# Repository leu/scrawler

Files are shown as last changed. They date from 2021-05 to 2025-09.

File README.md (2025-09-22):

# The Scrawler
The name of this keyboard is the Scrawler.

It was inspired by this YouTube video: https://www.youtube.com/watch?v=thOifuHs6eY. It was born of wanting to experiment with a hexagonal tiling layout for keyboards. I currently have no plans to continue work on this project, as it is time consuming and many of the challenges are in the domain of material science and physical design, and I would rather spend my time in my personal specialisation of programming and computer science. But in case you have any questions, feel free to reach out to me at in.lieu.of.leu@gmail.com!

This repository contains all of my notes, PCB designs, and CAD files for 3D print for the Scrawler.

Second prototype:


First prototype:
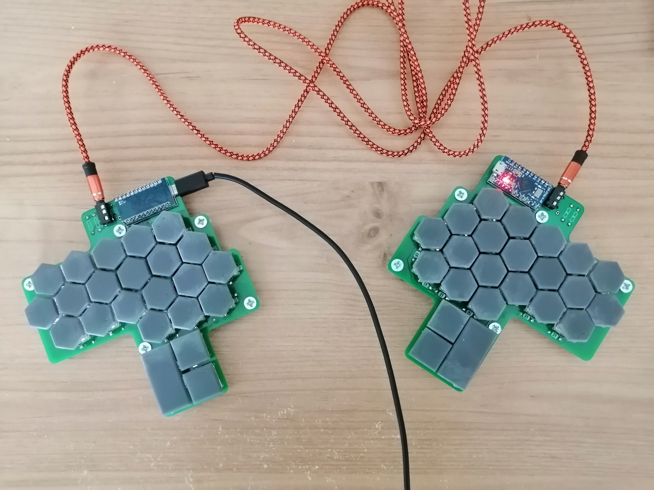
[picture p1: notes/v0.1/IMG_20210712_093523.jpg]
prototype both sides

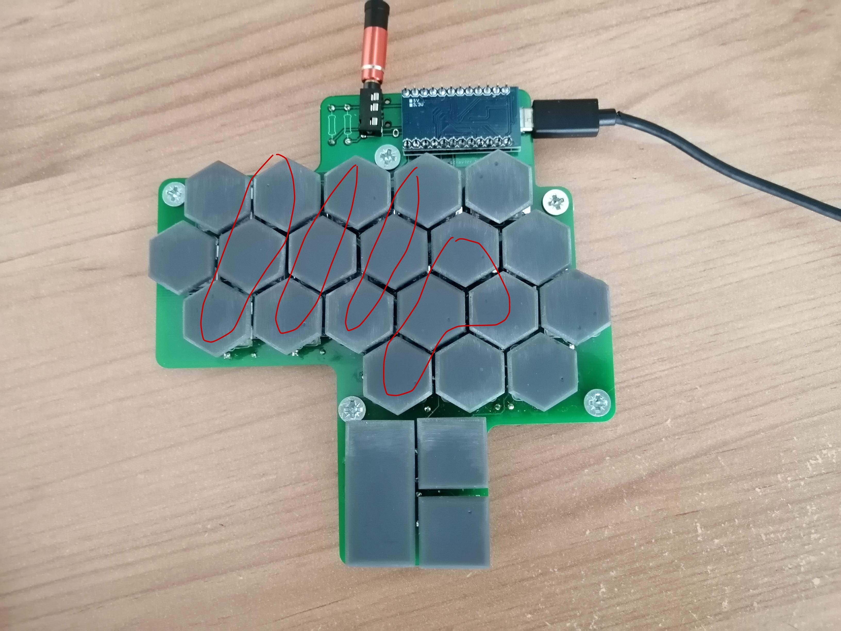
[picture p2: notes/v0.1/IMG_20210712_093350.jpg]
prototype left side

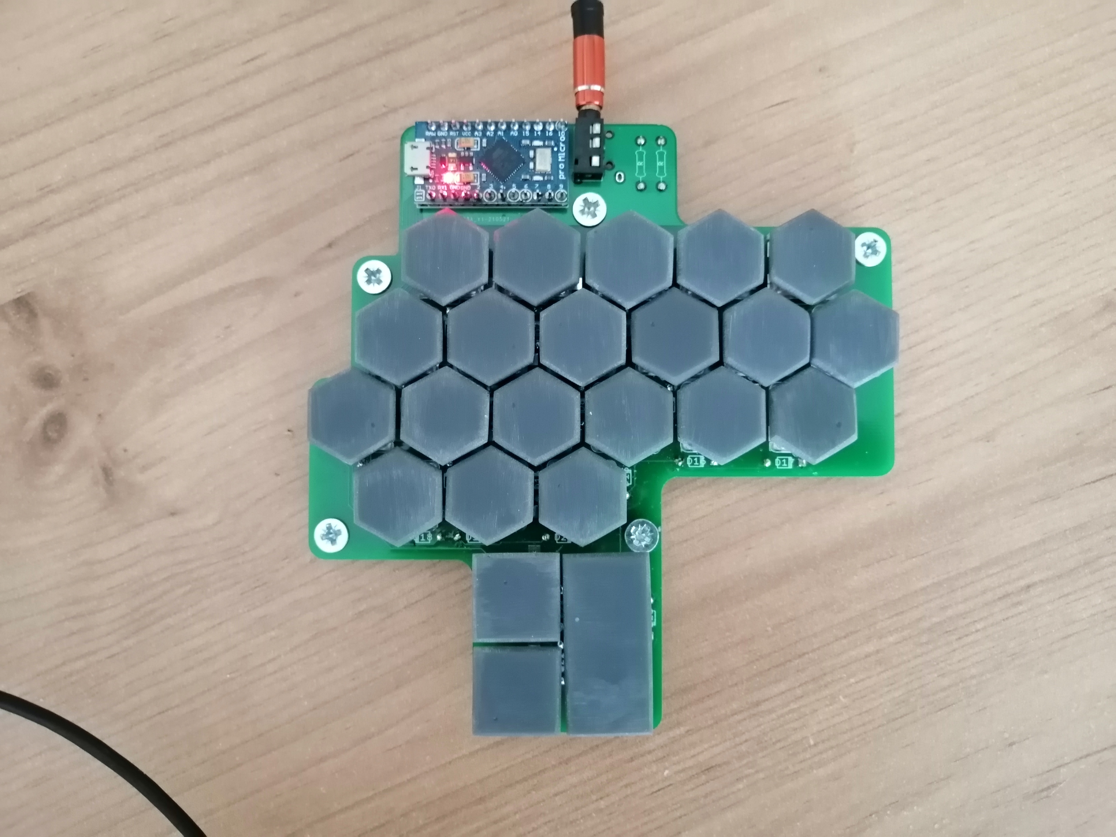
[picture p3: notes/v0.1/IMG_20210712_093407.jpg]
prototype right side


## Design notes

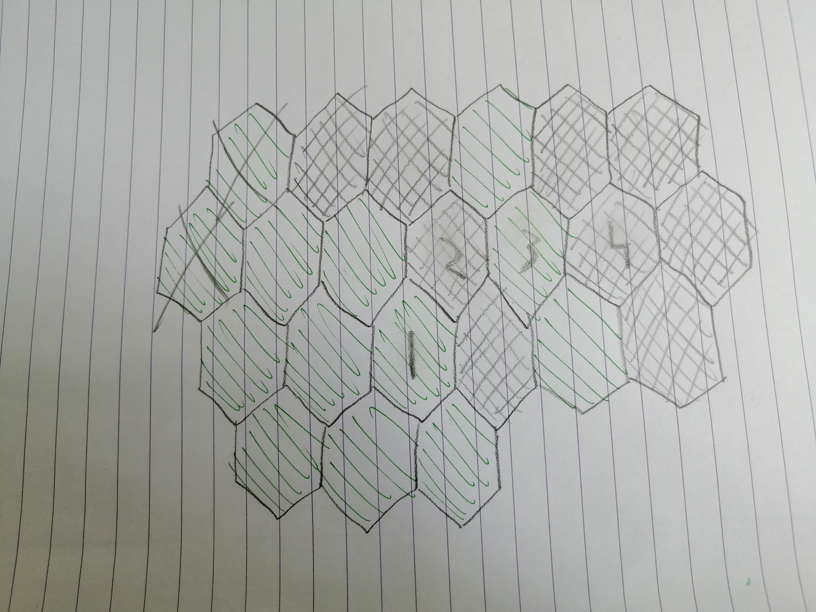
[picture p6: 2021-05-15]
notes/v0.1/layout.jpg

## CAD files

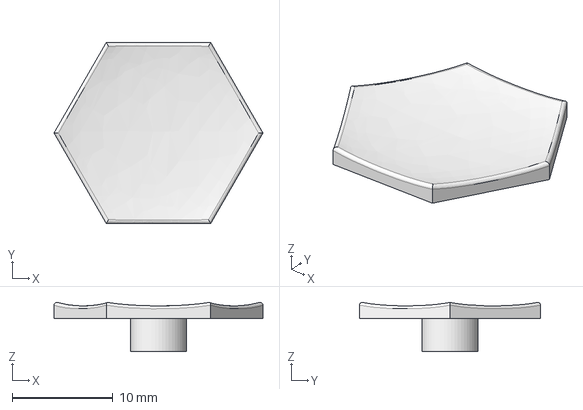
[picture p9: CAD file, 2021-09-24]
v1/keycaps/hexagonal/hex_keycap.FCStd
20.8 x 18.0 x 4.90 mm

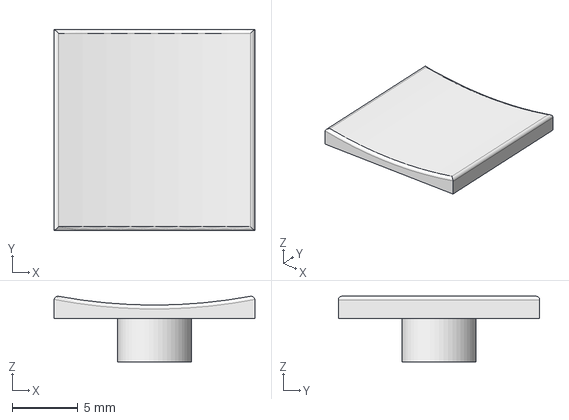
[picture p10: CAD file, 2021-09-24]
v1/keycaps/square/square.FCStd
15.2 x 15.2 x 4.97 mm

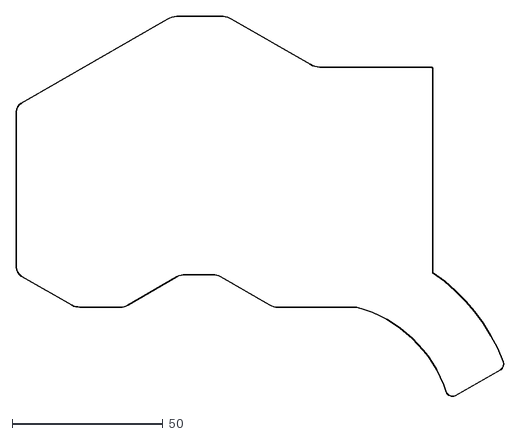
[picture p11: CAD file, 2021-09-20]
v1/plate/top_plate.dxf
161.9 x 126.1

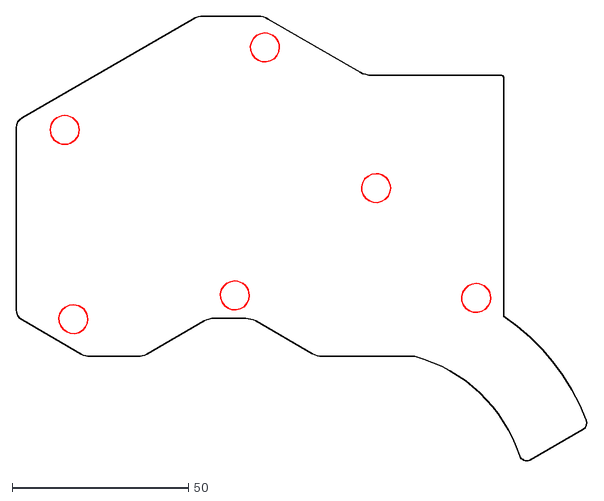
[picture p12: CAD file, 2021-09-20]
v1/plate/bottom_plate.dxf
161.9 x 126.1

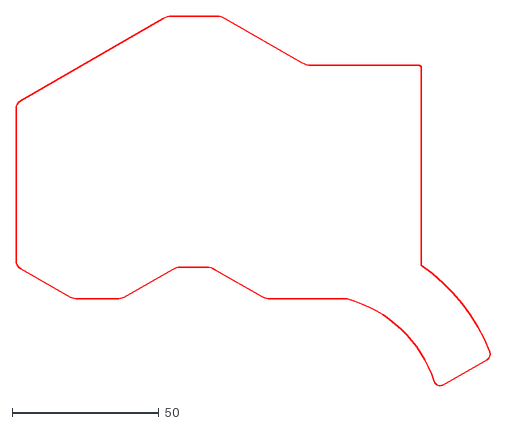
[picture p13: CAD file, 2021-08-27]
v1/plate/drawing.dxf
161.9 x 126.1

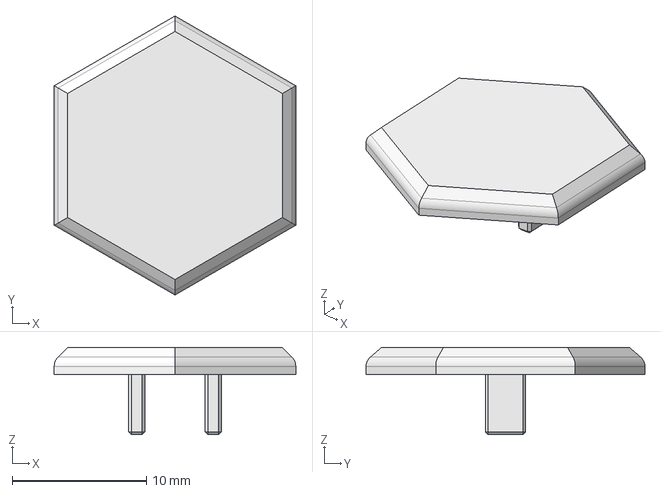
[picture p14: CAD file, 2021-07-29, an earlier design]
v0.1/3d_print/keycaps/hex/hex.step
18.0 x 20.8 x 6.49 mm

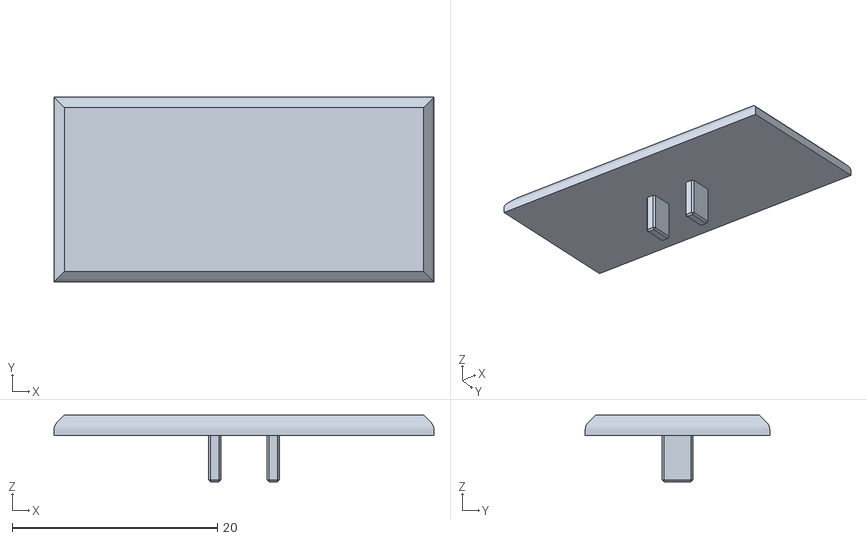
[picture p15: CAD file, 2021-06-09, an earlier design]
v0.1/3d_print/keycaps/rectangle/rectangle.stl
37.0 x 18.0 x 6.50

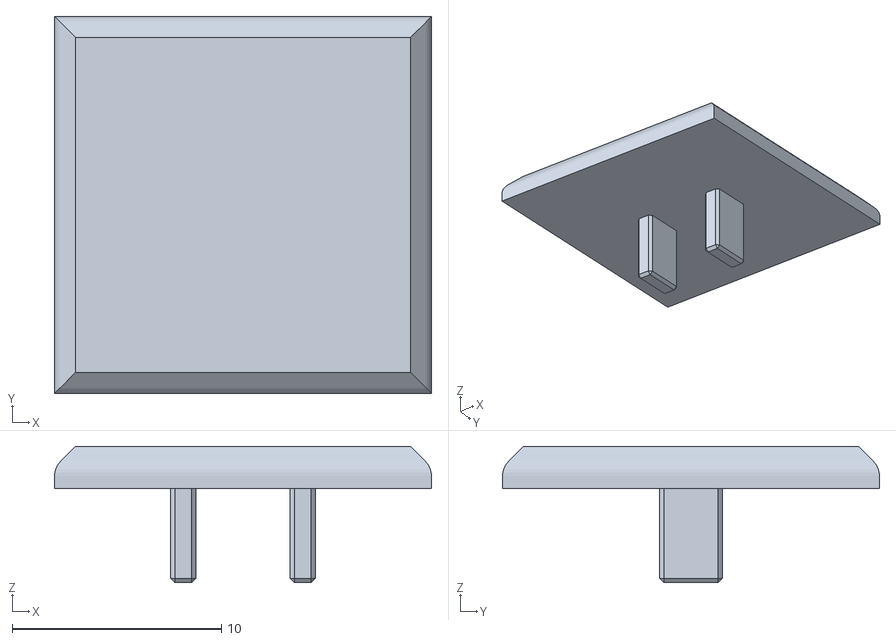
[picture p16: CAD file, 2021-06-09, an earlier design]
v0.1/3d_print/keycaps/square/square.stl
18.0 x 18.0 x 6.50

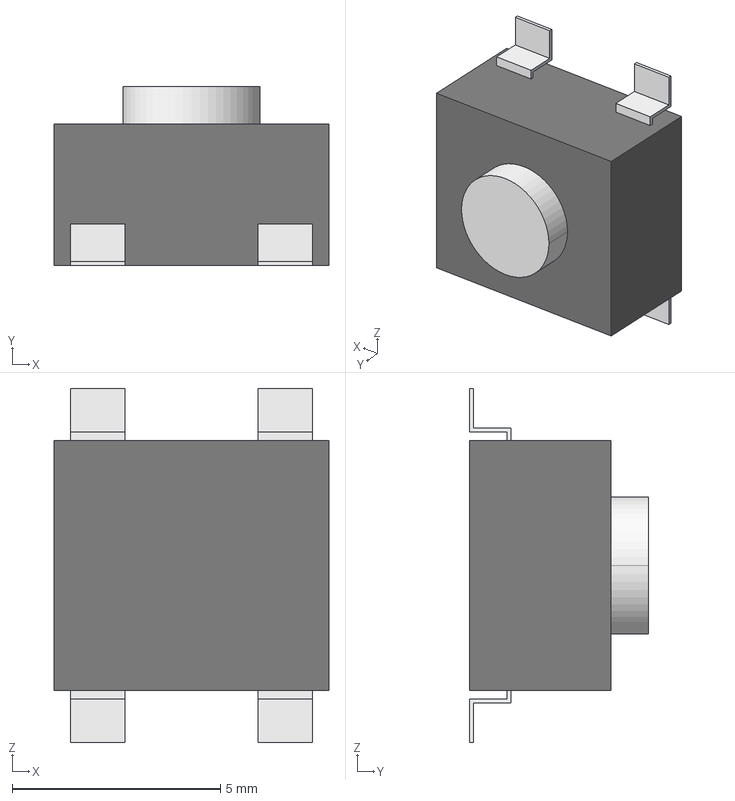
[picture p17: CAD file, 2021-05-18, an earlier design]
v0.1/pcb/reset-switch/B3S-1002/3D/B3S-1002.stp
6.60 x 4.30 x 8.50 mm

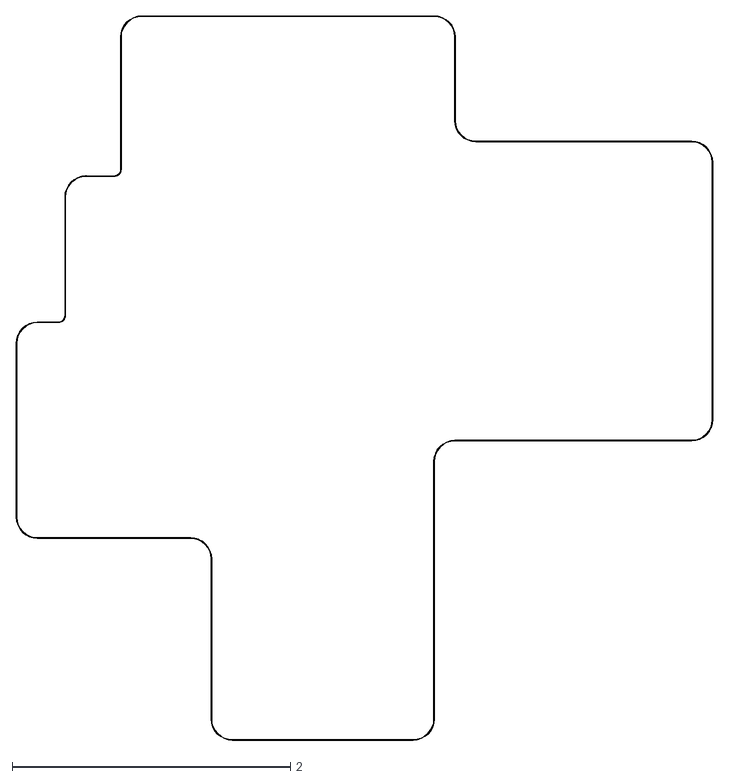
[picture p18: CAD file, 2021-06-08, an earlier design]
v0.1/pcb/svg/scrawler-Edge_Cuts.dxf
5.00 x 5.20

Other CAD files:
v0.1/3d_print/keycaps/hex/hex_cap.stl
v0.1/3d_print/keycaps/rectangle/rectangle-kailh-choc.FCStd
v0.1/3d_print/keycaps/square/square-kailh-choc.FCStd
v0.1/3d_print/keycaps/hex/hex-kailh-choc.FCStd
v0.1/pcb/reset-switch/B3S-1002/Allegro/b3s1002.psm
v0.1/pcb/reset-switch/B3S-1002/DEHDL/b3s_1002/chips/chips.prt

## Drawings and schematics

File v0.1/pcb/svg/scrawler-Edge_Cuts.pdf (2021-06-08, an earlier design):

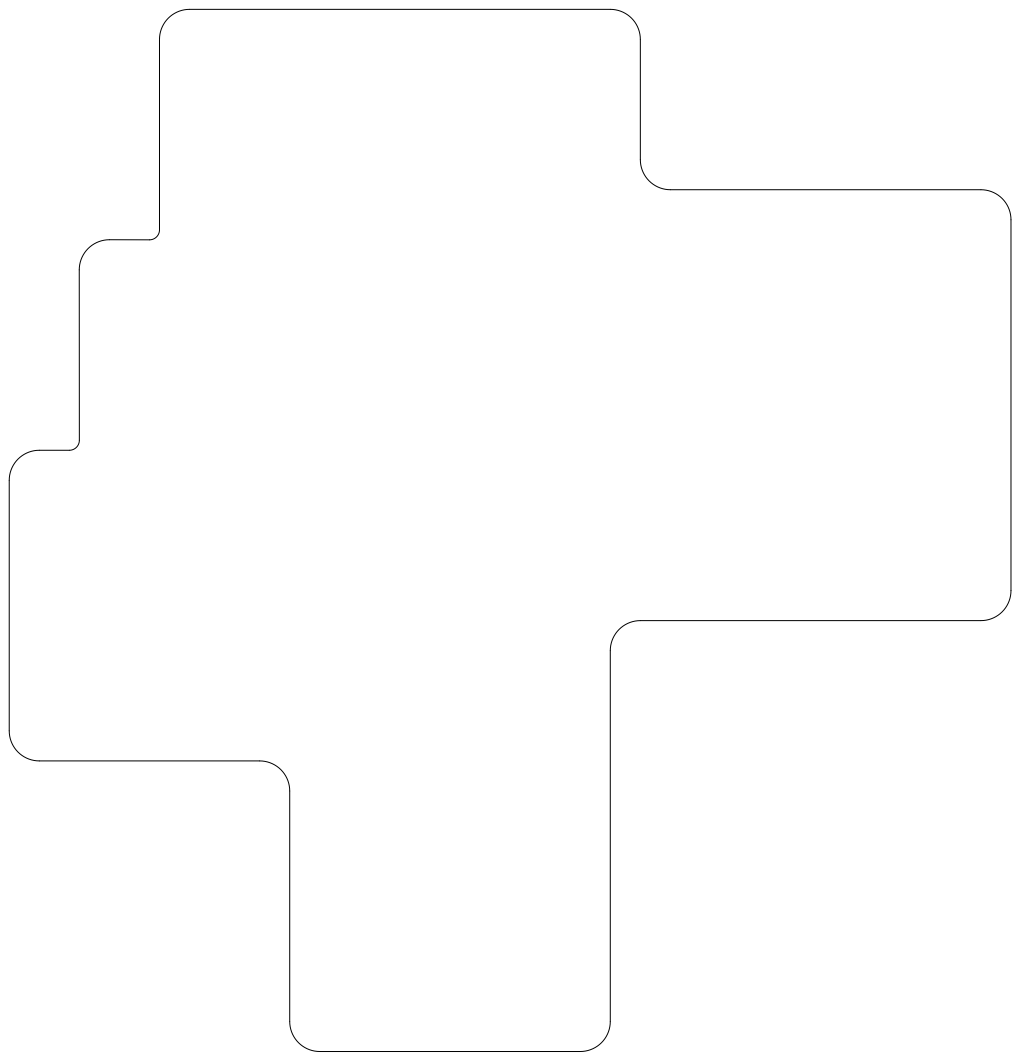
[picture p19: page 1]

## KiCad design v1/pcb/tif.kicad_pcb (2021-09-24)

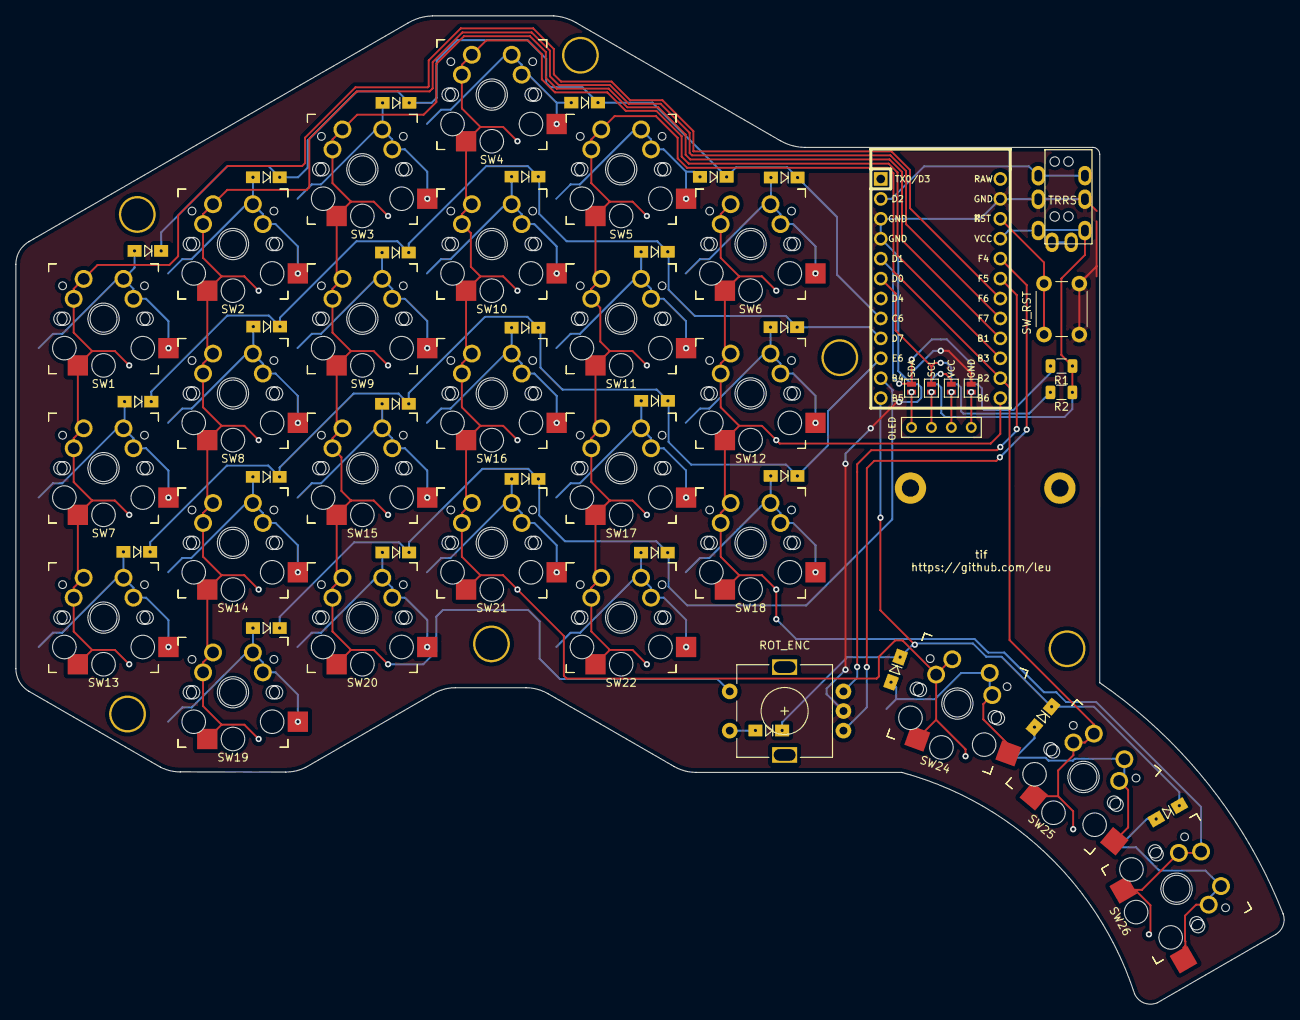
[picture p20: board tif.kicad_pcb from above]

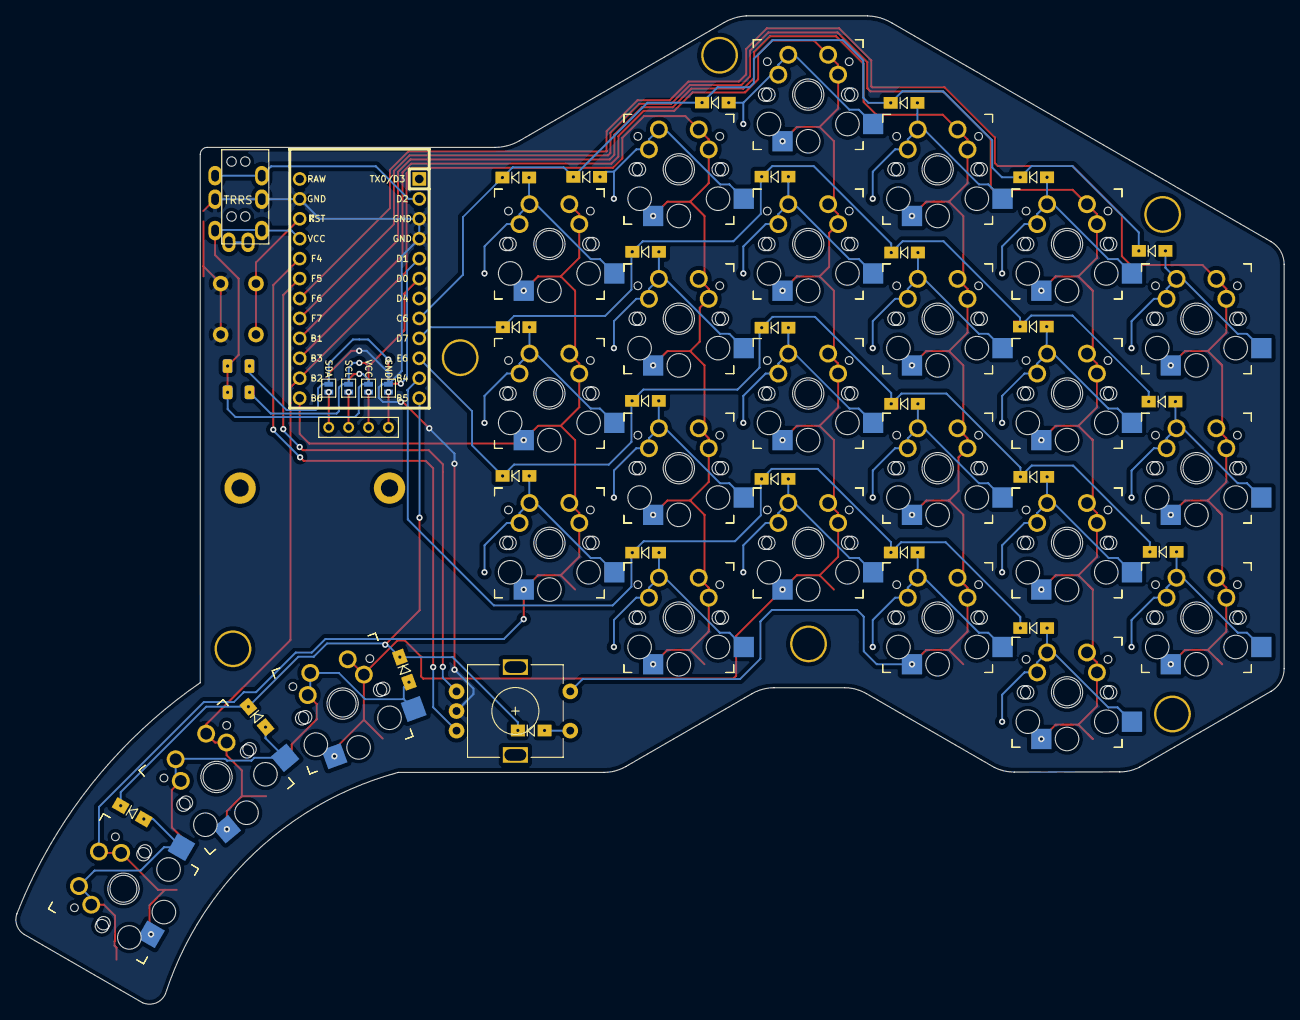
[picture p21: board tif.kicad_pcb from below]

Board: 2 copper layers, 161.7 x 126.0 mm, 99 parts (4 on the bottom side), 49 nets.

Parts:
D1, D2, D3, D4, D5, D6, D7, D8, D9, D10, D11, D12, D13, D14, D15, D16, D17, D18, D19, D20, D21, D22, D23, D24, D25, D26: D; Diode_SOD123
H1, H2, H3, H4, H5, H6: Hole; HOLE_M2_TH
H7, H8: Hole; M2_HOLE_PCB
J2: MJ-4PP-9
JP1, JP8: GND; Jumper
JP2, JP7: VCC; Jumper
JP3, JP6: SCL; Jumper
JP4, JP5: SDA; Jumper
OLED: OLED; OLED_4Pin
R1, R2: R; R_1206_DoubleSided
ROT_ENC: Rotary_Encoder_Switch; RotaryEncoder_Alps_EC11E-Switch_Vertical_H20mm-keebio_modif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
RSW1: SW_RST; SW_PUSH_6mm
SW1, SW2, SW3, SW4, SW5, SW6, SW7, SW8, SW9, SW10, SW11, SW12, SW13, SW14, SW15, SW16, SW17, SW18, SW19, SW20, SW21, SW22, SW24, SW25, SW26: SW_PUSH; MX_reversible
SW1B1, SW2B1, SW3B1, SW4B1, SW5B1, SW6B1, SW7B1, SW8B1, SW9B1, SW10B1, SW11B1, SW12B1, SW13B1, SW14B1, SW15B1, SW16B1, SW17B1, SW18B1, SW19B1, SW20B1, SW21B1, SW22B1, SW24B1, SW25B1, SW26B1: SW_PUSH; PG1350_socket_reversible
U1: ProMicro; ArduinoProMicro

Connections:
COL0: SW1.1, SW1B1.1, SW7.1, SW7B1.1, SW13.1, SW13B1.1, U1.18
COL1: SW2.1, SW2B1.1, SW8.1, SW8B1.1, SW14.1, SW14B1.1, SW19.1, SW19B1.1, U1.17
COL2: ROT_ENC.S1, SW3.1, SW3B1.1, SW9.1, SW9B1.1, SW15.1, SW15B1.1, SW20.1, SW20B1.1, U1.16
COL3: SW4.1, SW4B1.1, SW10.1, SW10B1.1, SW16.1, SW16B1.1, SW21.1, SW21B1.1, SW24.1, SW24B1.1, U1.15
COL4: SW5.1, SW5B1.1, SW11.1, SW11B1.1, SW17.1, SW17B1.1, SW22.1, SW22B1.1, SW25.1, SW25B1.1, U1.14
COL5: SW6.1, SW6B1.1, SW12.1, SW12B1.1, SW18.1, SW18B1.1, SW26.1, SW26B1.1, U1.13
DATA: J2.B, U1.2
ENCA: ROT_ENC.A, U1.20
ENCB: ROT_ENC.B, U1.19
GND: J2.C, JP1.2, JP8.2, ROT_ENC.C, RSW1.1, U1.3, U1.4, U1.23
unnamed: D1.2, SW1.2, SW1B1.2
unnamed: D2.2, SW2.2, SW2B1.2
unnamed: D3.2, SW3.2, SW3B1.2
unnamed: D4.2, SW4.2, SW4B1.2
unnamed: D5.2, SW5.2, SW5B1.2
unnamed: D6.2, SW6.2, SW6B1.2
unnamed: D7.2, SW7.2, SW7B1.2
unnamed: D8.2, SW8.2, SW8B1.2
unnamed: D9.2, SW9.2, SW9B1.2
unnamed: D10.2, SW10.2, SW10B1.2
unnamed: D11.2, SW11.2, SW11B1.2
unnamed: D12.2, SW12.2, SW12B1.2
unnamed: D13.2, SW13.2, SW13B1.2
unnamed: D14.2, SW14.2, SW14B1.2
unnamed: D15.2, SW15.2, SW15B1.2
unnamed: D16.2, SW16.2, SW16B1.2
unnamed: D17.2, SW17.2, SW17B1.2
unnamed: D18.2, SW18.2, SW18B1.2
unnamed: D19.2, SW19.2, SW19B1.2
unnamed: D20.2, SW20.2, SW20B1.2
unnamed: D21.2, SW21.2, SW21B1.2
unnamed: D22.2, SW22.2, SW22B1.2
unnamed: D24.2, SW24.2, SW24B1.2
unnamed: D25.2, SW25.2, SW25B1.2
unnamed: D26.2, SW26.2, SW26B1.2
unnamed: JP4.1, JP8.1, OLED.1
unnamed: JP3.1, JP7.1, OLED.2
unnamed: JP2.1, JP6.1, OLED.3
unnamed: JP1.1, JP5.1, OLED.4
RESET: RSW1.2, U1.22
ROW0: D1.1, D2.1, D3.1, D4.1, D5.1, D6.1, U1.8
ROW1: D7.1, D8.1, D9.1, D10.1, D11.1, D12.1, U1.9
ROW2: D13.1, D14.1, D15.1, D16.1, D17.1, D18.1, U1.10
ROW3: D19.1, D20.1, D21.1, D22.1, U1.11
ROW4: D23.1, D24.1, D25.1, D26.1, U1.12
SCL: JP3.2, JP6.2, R2.2, U1.6
SDA: JP4.2, JP5.2, R1.2, U1.5
SW23B: D23.2, ROT_ENC.S2
VCC: J2.D, JP2.2, JP7.2, R1.1, R2.1, U1.21

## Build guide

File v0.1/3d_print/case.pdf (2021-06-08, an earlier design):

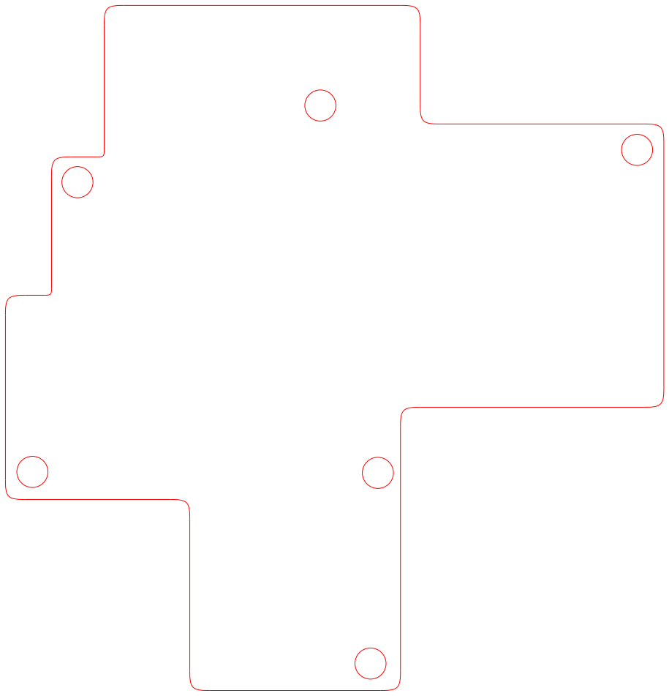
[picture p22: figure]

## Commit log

2021-05-10 files from desktop
    [1.FCStd, 44ML_ATM.step, circle-stub.FCStd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]
2021-05-10 fix pcb
2021-05-10 fixed pcb
2021-05-12 update design file
    [circle-stub.FCStd, hex-kailh-choc.FCStd, scrawler.sch]
2021-05-12 started design, made components list
    [44ML_ATM.step, scrawler.sch]
2021-05-12 laptop commit
    [scrawler.sch]
2021-05-18 decided no resistors/switch for now
    [B3S-1002.stp, EDI2CAP.CFG, b3s1002.psm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]
2021-05-19 started physical pcb
    [scrawler.sch]
2021-05-20 finished routing
    [scrawler.kicad_pcb]
2021-05-28 clean root dir
    [hex-kailh-choc.FCStd, scrawler (copy).kicad_pcb, scrawler.sch]
2021-06-02 made rectangle keycap and bottom plate template
    [case.FCStd, hex-kailh-choc.FCStd, rectangle-kailh-choc.FCStd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]
2021-06-08 stl file
    [case.FCStd, hex-kailh-choc.FCStd, hex_cap.stl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]
2021-06-08 case stl
    [case.stl]
2021-06-08 kicad dxf pdf
    [scrawler-Edge_Cuts.dxf]
2021-06-08 inkscape case
    [case_r12.dxf, case_r14.dxf]
2021-06-08 freecad dxf
    [case.dxf, case.stl, dfg.dxf]
2021-06-08 new inkscape dxf
    [case.stl, case_r12.dxf, case_r14.dxf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]
2021-06-09 stl files
    [case.FCStd, rectangle-kailh-choc.FCStd, rectangle.stl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]
2021-07-12 add prototype images
2021-07-12 showcase prototype
2021-07-29 restructure for versions, clean design notes
    [B3S-1002.stp, EDI2CAP.CFG, b3s1002.psm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]
2021-08-21 add submodules
    [scrawler.kicad_pcb, scrawler.sch]
2021-08-21 pcb prfinished
    [scrawler.sch]
2021-08-22 assigned footprints
    [scrawler.sch]
2021-08-22 placed main switches in physical pcb
    [scrawler.kicad_pcb, scrawler.sch]
2021-08-26 pcb done
    [pricing.ods, scrawler.kicad_pcb, scrawler.sch]
2021-08-27 pcb plate finished
    [drawing.dxf, scrawler.kicad_pcb]
2021-08-28 generated gerber files
    [scrawler-B_Cu.gbr, scrawler-B_Mask.gbr, scrawler-B_Paste.gbr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]
2021-09-20 pcb plate
    [scrawler-B_Mask.gbr, scrawler-B_Paste.gbr, scrawler-B_SilkS.gbr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]
2021-09-20 renamed to tif
    [tif.kicad_pcb, tif.sch]
2021-09-20 keycap stem work
    [no_border.FCStd, square.FCStd]
2021-09-24 started on top plate
    [cone.FCStd, hex_keycap.FCStd, hexagonal_keycap.FCStd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]
2021-09-24 hole for rotary encoder
    [tif.kicad_pcb]
2021-09-24 finished top plate switch mounts, switched holes on plate
    [tif.kicad_pcb, tif.sch]
2021-09-24 top plate outline done
    [tif.kicad_pcb]
2021-09-24 top plate finished
    [tif.kicad_pcb]
2021-09-24 bottom plate finished
    [scrawler-B_Cu.gbr, scrawler-B_Mask.gbr, scrawler-B_Paste.gbr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]
2025-09-22 Include image of second prototype
